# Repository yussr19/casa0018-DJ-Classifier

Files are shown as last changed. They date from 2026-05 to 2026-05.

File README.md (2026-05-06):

# DJ Sound Classifier — CASA0018

<div align="center">

**Author:** yussr19  
**GitHub:** [casa0018-DJ-Classifier](https://github.com/yussr19/casa0018-DJ-Classifier)  
**Edge Impulse Project:** [Public Project Link](https://studio.edgeimpulse.com/public/965867/live)

<br>

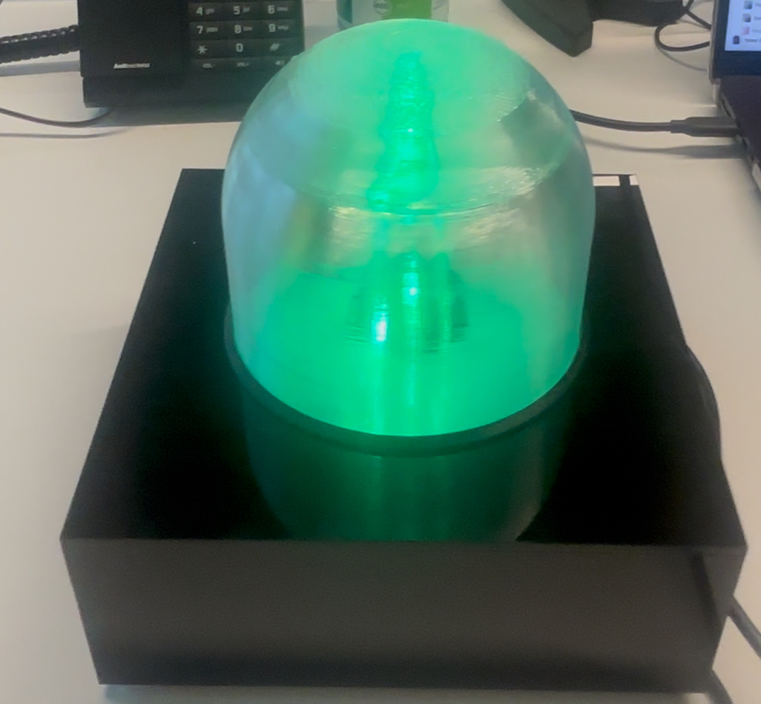
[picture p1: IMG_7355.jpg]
DJ Sound Classifier enclosure


*Custom 3D-printed enclosure showing a control noise (green) classification*

</div>

---

# Overview

The **DJ Sound Classifier** is a real-time embedded audio classification system that detects acoustic events in DJ sets and triggers reactive LED lighting effects entirely on-device — no cloud connection required.

The system classifies three audio events:

| Class | LED Response |
|---|---|
| **Bass drop** | 🔵 Blue chasing effect |
| **Kick drop** | 🔴 Solid red |
| **Control noise** | 🟢 Solid green |

---

# Motivation

The UK's grassroots music venue scene has faced a prolonged financial crisis, with over 125 venues closing in 2023 alone due to rising operational costs, including professional lighting and production systems.

This project explores whether **edge machine learning** can provide a low-cost alternative to commercial audio-reactive lighting systems for resource-constrained venues.

---

# Hardware

| Component | Details | Approx. Cost |
|---|---|---|
| Arduino Nano 33 BLE Sense | Microcontroller with onboard microphone | £35 |
| WS2812B NeoPixel Strip (16 LEDs) | Addressable RGB LEDs | £5 |
| 3×AA Battery Pack | 4.5V power supply | £2 |
| 330Ω Resistor | Data-line protection | <£1 |
| 100µF Capacitor | Power smoothing | <£1 |
| Breadboard + Jumper Wires | Circuit assembly | £3 |
| 3D Printed Enclosure | `DOME.stl` + `light_boxx.stl` | ~£2 |

**Estimated total cost:** ~£48

---

# Reproducing the Project

## Step 1 — Print the Enclosure

Print both STL files from the `/enclosure` folder:

- `light_boxx.stl` — base housing for the Arduino and breadboard
- `DOME.stl` — light-diffusing dome cover

### Recommended Settings

- PLA
- 0.2mm layer height
- 20% infill

For best diffusion, print the dome using **white or translucent filament**.

---

# Step 2 — Assemble the Circuit

## Wiring Diagram

```text
Battery (+) ─────────────────────────────── LED Strip 5V
Battery (-) ─────────────────────────────── LED Strip GND
Battery (-) ─────────────────────────────── Arduino GND

Capacitor (+) ───────────────────────────── LED Strip 5V
Capacitor (-) ───────────────────────────── LED Strip GND

Arduino D6 ─── 330Ω resistor ───────────── LED Strip DIN
```

### Important Notes

- The **330Ω resistor** protects the first LED from voltage spikes.
- The **100µF capacitor** stabilises the power rail and prevents brownouts or Arduino resets.
- All components must share a **common ground**.

Place the Arduino and breadboard inside `light_boxx.stl`, then wrap the LED strip around the inside of the dome.

---

# Step 3 — Set Up Edge Impulse

You can either use the pretrained model or retrain the system from scratch.

---

## Option A — Use the Existing Model (Recommended)

1. Open the public Edge Impulse project:  
   https://studio.edgeimpulse.com/public/965867/live

2. Click **Clone this project**

3. Navigate to:

```text
Deployment → Arduino Library → Build
```

4. Download the generated ZIP library.

---

## Option B — Retrain the Model

### Install Edge Impulse CLI

```bash
npm install -g edge-impulse-cli
edge-impulse-daemon --clean
```

### Collect Data

Record:
- 2-second samples
- 16kHz mono WAV
- ~115 samples per class

### Classes

| Class | Description |
|---|---|
| `bass_drop` | Sustained bass-heavy sections |
| `kick_drop` | Rhythmic kick drum patterns |
| `control_noise` | Ambient crowd/room noise |

---

## Create the Impulse

### Input Parameters

- Window size: 2000ms
- Window increase: 500ms
- Frequency: 16000Hz

### Processing Block

```text
Audio (MFE)
```

### Learning Block

```text
Classification
```

---

## MFE Parameters

| Parameter | Value |
|---|---|
| Frame length | 0.02 |
| Frame stride | 0.01 |
| Filters | 6 |
| FFT length | 256 |
| Low frequency | 0 |
| High frequency | 300 |

---

## Training Settings

| Parameter | Value |
|---|---|
| Epochs | 100 |
| Learning rate | 0.005 |
| Batch size | 32 |
| Data augmentation | Off |

### Keras Expert Mode

Update the reshape layer:

```python
Reshape((int(input_length / 6), 6))
```

---

# Step 4 — Install Arduino Libraries

## Install NeoPixel Library

Arduino IDE:

```text
Tools → Manage Libraries → Adafruit NeoPixel → Install
```

## Install Edge Impulse Library

```text
Sketch → Include Library → Add .ZIP Library
```

Select the ZIP downloaded from Edge Impulse.

---

# Step 5 — Upload the Arduino Sketch

1. Open:

```text
DJ_LED2/DJ_LED2.ino
```

2. Select board:

```text
Arduino Nano 33 BLE Sense
```

3. Select the correct port and click **Upload**

---

## Optional: Upload via bossac

```bash
ls /dev/cu.usbmodem*

bossac -p /dev/cu.usbmodem[PORT] -e -w -v -R DJ_LED2.ino.bin
```

---

# Step 6 — Power and Test

1. Disconnect USB
2. Connect the 3×AA battery pack
3. The LEDs flash white on startup to confirm the system is active

## Test Responses

| Audio Event | LED Behaviour |
|---|---|
| Bass-heavy music | 🔵 Blue chasing |
| Kick-heavy patterns | 🔴 Solid red |
| Ambient noise / silence | 🟢 Solid green |

> Best performance occurs when positioned approximately 30–50cm from the speaker.

---

# ML Model Details

| Feature | Value |
|---|---|
| Platform | Edge Impulse |
| Project ID | 965867 |
| Preprocessing | MFE, 300Hz LPF |
| Filters | 6 |
| FFT Length | 256 |
| Architecture | 1D CNN |
| Deployment | INT8 quantised (EON Compiler) |
| RAM Usage | 13.8KB |
| Flash Usage | 46.5KB |
| Inference Time | ~5ms |

---

# Dataset

| Class | Samples |
|---|---|
| bass_drop | 116 |
| kick_drop | 115 |
| control_noise | 115 |
| **Total** | **346** |

### Dataset Split

- 80% training
- 20% testing

---

# Results Summary

| Experiment | Accuracy | Weighted F1 |
|---|---|---|
| Broadband Spectrogram | 30.0% | 0.14 |
| MFE 200Hz | 52.9% | 0.51 |
| **MFE 300Hz (Best)** | **57.1%** | **0.58** |
| MFE 500Hz | 57.1% | 0.57 |
| MFCC Broadband | 52.9% | 0.53 |
| MFCC 300Hz | 44.3% | 0.42 |
| Venue Test 1 | 21.74% | 0.37 |
| Venue Test 2 | 35.71% | 0.46 |

---

# Known Limitations

- Significant domain gap between home and live venue recordings
- Kick drops overlap spectrally with bass drops below 300Hz
- Environmental acoustics reduce reliability in crowded venues
- Direct mixer line-in would substantially improve performance

---

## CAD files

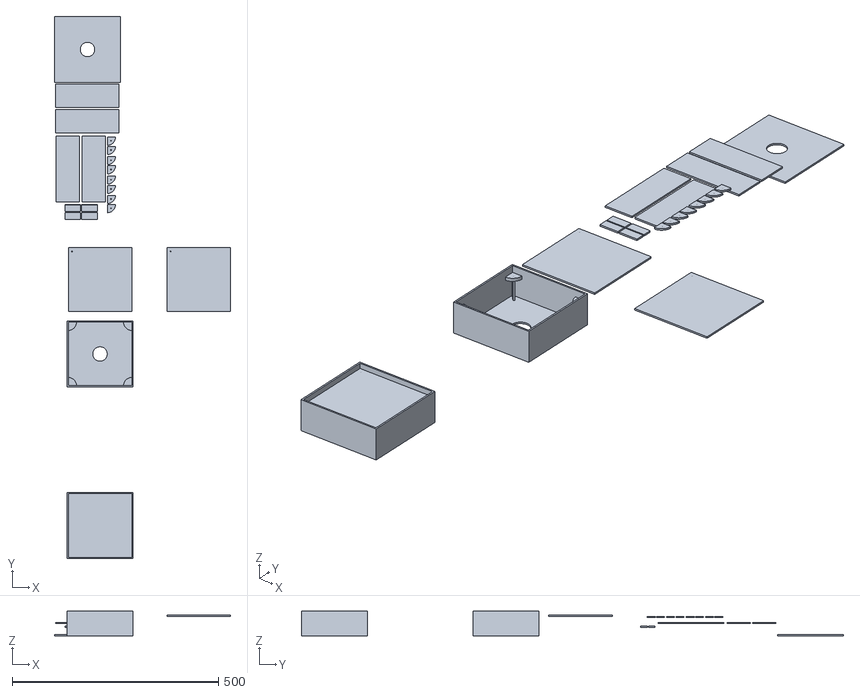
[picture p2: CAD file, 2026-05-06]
enclosure /light boxx.stl
426.5 x 1312.9 x 60.0

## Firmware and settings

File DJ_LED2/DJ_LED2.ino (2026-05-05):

#define EIDSP_QUANTIZE_FILTERBANK 0
#include <DJ_classifier_casa0018_inferencing.h>
#include <PDM.h>
#include <Adafruit_NeoPixel.h>

#define LED_PIN 6
#define LED_COUNT 16
Adafruit_NeoPixel strip(LED_COUNT, LED_PIN, NEO_GRB + NEO_KHZ800);

typedef struct {
    int16_t *buffer;
    uint8_t buf_ready;
    uint32_t buf_count;
    uint32_t n_samples;
} inference_t;

static inference_t inference;
static signed short sampleBuffer[2048];
static bool debug_nn = false;

static void pdm_data_ready_inference_callback(void)
{
    int bytesAvailable = PDM.available();
    int bytesRead = PDM.read((char *)&sampleBuffer[0], bytesAvailable);
    if (inference.buf_ready == 0) {
        for(int i = 0; i < bytesRead>>1; i++) {
            inference.buffer[inference.buf_count++] = sampleBuffer[i];
            if(inference.buf_count >= inference.n_samples) {
                inference.buf_count = 0;
                inference.buf_ready = 1;
                break;
            }
        }
    }
}

static bool microphone_inference_start(uint32_t n_samples)
{
    inference.buffer = (int16_t *)malloc(n_samples * sizeof(int16_t));
    if(inference.buffer == NULL) { return false; }
    inference.buf_count = 0;
    inference.n_samples = n_samples;
    inference.buf_ready = 0;
    PDM.onReceive(&pdm_data_ready_inference_callback);
    PDM.setBufferSize(4096);
    if (!PDM.begin(1, EI_CLASSIFIER_FREQUENCY)) {
        ei_printf("Failed to start PDM!");
        free(inference.buffer);
        return false;
    }
    PDM.setGain(127);
    return true;
}

static bool microphone_inference_record(void)
{
    inference.buf_ready = 0;
    inference.buf_count = 0;
    while(inference.buf_ready == 0) { delay(10); }
    return true;
}

static int microphone_audio_signal_get_data(size_t offset, size_t length, float *out_ptr)
{
    numpy::int16_to_float(&inference.buffer[offset], out_ptr, length);
    return 0;
}

void setup()
{
    Serial.begin(115200);
    strip.begin();
    strip.setBrightness(80);
    strip.fill(strip.Color(255, 255, 255));
    strip.show();
    delay(1000);
    strip.clear();
    strip.show();
    if (microphone_inference_start(EI_CLASSIFIER_RAW_SAMPLE_COUNT) == false) {
        ei_printf("ERR: Could not allocate audio buffer\r\n");
        return;
    }
}

void loop()
{
    bool m = microphone_inference_record();
    if (!m) { return; }
    signal_t signal;
    signal.total_length = EI_CLASSIFIER_RAW_SAMPLE_COUNT;
    signal.get_data = &microphone_audio_signal_get_data;
    ei_impulse_result_t result = { 0 };
    EI_IMPULSE_ERROR r = run_classifier(&signal, &result, debug_nn);
    if (r != EI_IMPULSE_OK) { return; }
    float maxVal = 0;
    int maxIdx = 0;
    for (int i = 0; i < EI_CLASSIFIER_LABEL_COUNT; i++) {
        ei_printf("%s: %.5f\n", result.classification[i].label, result.classification[i].value);
        if (result.classification[i].value > maxVal) {
            maxVal = result.classification[i].value;
            maxIdx = i;
        }
    }
    if (maxIdx == 0) {
        // bass drop - blue chase effect
        for(int j = 0; j < 3; j++) {
            for(int i = 0; i < LED_COUNT; i++) {
                strip.clear();
                strip.setPixelColor(i, strip.Color(0, 0, 255));
                strip.setPixelColor((i + LED_COUNT/2) % LED_COUNT, strip.Color(0, 0, 128));
                strip.show();
                delay(30);
            }
        }
    } else if (maxIdx == 2) {
        strip.fill(strip.Color(255, 0, 0));
        strip.show();
    } else {
        strip.fill(strip.Color(0, 255, 0));
        strip.show();
    }
}

#if !defined(EI_CLASSIFIER_SENSOR) || EI_CLASSIFIER_SENSOR != EI_CLASSIFIER_SENSOR_MICROPHONE
#error "Invalid model for current sensor."
#endif

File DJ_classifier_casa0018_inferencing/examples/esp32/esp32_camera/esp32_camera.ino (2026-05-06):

/* Edge Impulse Arduino examples
 * Copyright (c) 2022 EdgeImpulse Inc.
 *
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
 * THE SOFTWARE IS PROVIDED "AS IS", WITHOUT WARRANTY OF ANY KIND, EXPRESS OR
 * IMPLIED, INCLUDING BUT NOT LIMITED TO THE WARRANTIES OF MERCHANTABILITY,
 * FITNESS FOR A PARTICULAR PURPOSE AND NONINFRINGEMENT. IN NO EVENT SHALL THE
 * AUTHORS OR COPYRIGHT HOLDERS BE LIABLE FOR ANY CLAIM, DAMAGES OR OTHER
 * LIABILITY, WHETHER IN AN ACTION OF CONTRACT, TORT OR OTHERWISE, ARISING FROM,
 * OUT OF OR IN CONNECTION WITH THE SOFTWARE OR THE USE OR OTHER DEALINGS IN THE
 * SOFTWARE.
 */

// These sketches are tested with 2.0.4 ESP32 Arduino Core
// https://github.com/espressif/arduino-esp32/releases/tag/2.0.4

/* Includes ---------------------------------------------------------------- */
#include <DJ_classifier_casa0018_inferencing.h>
#include "edge-impulse-sdk/dsp/image/image.hpp"

#include "esp_camera.h"

// Select camera model - find more camera models in camera_pins.h file here
// https://github.com/espressif/arduino-esp32/blob/master/libraries/ESP32/examples/Camera/CameraWebServer/camera_pins.h

#define CAMERA_MODEL_ESP_EYE // Has PSRAM
//#define CAMERA_MODEL_AI_THINKER // Has PSRAM

#if defined(CAMERA_MODEL_ESP_EYE)
#define PWDN_GPIO_NUM    -1
#define RESET_GPIO_NUM   -1
#define XCLK_GPIO_NUM    4
#define SIOD_GPIO_NUM    18
#define SIOC_GPIO_NUM    23

#define Y9_GPIO_NUM      36
#define Y8_GPIO_NUM      37
#define Y7_GPIO_NUM      38
#define Y6_GPIO_NUM      39
#define Y5_GPIO_NUM      35
#define Y4_GPIO_NUM      14
#define Y3_GPIO_NUM      13
#define Y2_GPIO_NUM      34
#define VSYNC_GPIO_NUM   5
#define HREF_GPIO_NUM    27
#define PCLK_GPIO_NUM    25

#elif defined(CAMERA_MODEL_AI_THINKER)
#define PWDN_GPIO_NUM     32
#define RESET_GPIO_NUM    -1
#define XCLK_GPIO_NUM      0
#define SIOD_GPIO_NUM     26
#define SIOC_GPIO_NUM     27

#define Y9_GPIO_NUM       35
#define Y8_GPIO_NUM       34
#define Y7_GPIO_NUM       39
#define Y6_GPIO_NUM       36
#define Y5_GPIO_NUM       21
#define Y4_GPIO_NUM       19
#define Y3_GPIO_NUM       18
#define Y2_GPIO_NUM        5
#define VSYNC_GPIO_NUM    25
#define HREF_GPIO_NUM     23
#define PCLK_GPIO_NUM     22

#else
#error "Camera model not selected"
#endif

/* Constant defines -------------------------------------------------------- */
#define EI_CAMERA_RAW_FRAME_BUFFER_COLS           320
#define EI_CAMERA_RAW_FRAME_BUFFER_ROWS           240
#define EI_CAMERA_FRAME_BYTE_SIZE                 3

/* Private variables ------------------------------------------------------- */
static bool debug_nn = false; // Set this to true to see e.g. features generated from the raw signal
static bool is_initialised = false;
uint8_t *snapshot_buf; //points to the output of the capture

static camera_config_t camera_config = {
    .pin_pwdn = PWDN_GPIO_NUM,
    .pin_reset = RESET_GPIO_NUM,
    .pin_xclk = XCLK_GPIO_NUM,
    .pin_sscb_sda = SIOD_GPIO_NUM,
    .pin_sscb_scl = SIOC_GPIO_NUM,

    .pin_d7 = Y9_GPIO_NUM,
    .pin_d6 = Y8_GPIO_NUM,
    .pin_d5 = Y7_GPIO_NUM,
    .pin_d4 = Y6_GPIO_NUM,
    .pin_d3 = Y5_GPIO_NUM,
    .pin_d2 = Y4_GPIO_NUM,
    .pin_d1 = Y3_GPIO_NUM,
    .pin_d0 = Y2_GPIO_NUM,
    .pin_vsync = VSYNC_GPIO_NUM,
    .pin_href = HREF_GPIO_NUM,
    .pin_pclk = PCLK_GPIO_NUM,

    //XCLK 20MHz or 10MHz for OV2640 double FPS (Experimental)
    .xclk_freq_hz = 20000000,
    .ledc_timer = LEDC_TIMER_0,
    .ledc_channel = LEDC_CHANNEL_0,

    .pixel_format = PIXFORMAT_JPEG, //YUV422,GRAYSCALE,RGB565,JPEG
    .frame_size = FRAMESIZE_QVGA,    //QQVGA-UXGA Do not use sizes above QVGA when not JPEG

    .jpeg_quality = 12, //0-63 lower number means higher quality
    .fb_count = 1,       //if more than one, i2s runs in continuous mode. Use only with JPEG
    .fb_location = CAMERA_FB_IN_PSRAM,
    .grab_mode = CAMERA_GRAB_WHEN_EMPTY,
};

/* Function definitions ------------------------------------------------------- */
bool ei_camera_init(void);
void ei_camera_deinit(void);
bool ei_camera_capture(uint32_t img_width, uint32_t img_height, uint8_t *out_buf) ;

/**
* @brief      Arduino setup function
*/
void setup()
{
    // put your setup code here, to run once:
    Serial.begin(115200);
    //comment out the below line to start inference immediately after upload
    while (!Serial);
    Serial.println("Edge Impulse Inferencing Demo");
    if (ei_camera_init() == false) {
        ei_printf("Failed to initialize Camera!\r\n");
    }
    else {
        ei_printf("Camera initialized\r\n");
    }

    ei_printf("\nStarting continious inference in 2 seconds...\n");
    ei_sleep(2000);
}

/**
* @brief      Get data and run inferencing
*
* @param[in]  debug  Get debug info if true
*/
void loop()
{

    // instead of wait_ms, we'll wait on the signal, this allows threads to cancel us...
    if (ei_sleep(5) != EI_IMPULSE_OK) {
        return;
    }

    snapshot_buf = (uint8_t*)malloc(EI_CAMERA_RAW_FRAME_BUFFER_COLS * EI_CAMERA_RAW_FRAME_BUFFER_ROWS * EI_CAMERA_FRAME_BYTE_SIZE);

    // check if allocation was successful
    if(snapshot_buf == nullptr) {
        ei_printf("ERR: Failed to allocate snapshot buffer!\n");
        return;
    }

    ei::signal_t signal;
    signal.total_length = EI_CLASSIFIER_INPUT_WIDTH * EI_CLASSIFIER_INPUT_HEIGHT;
    signal.get_data = &ei_camera_get_data;

    if (ei_camera_capture((size_t)EI_CLASSIFIER_INPUT_WIDTH, (size_t)EI_CLASSIFIER_INPUT_HEIGHT, snapshot_buf) == false) {
        ei_printf("Failed to capture image\r\n");
        free(snapshot_buf);
        return;
    }

    // Run the classifier
    ei_impulse_result_t result = { 0 };

    EI_IMPULSE_ERROR err = run_classifier(&signal, &result, debug_nn);
    if (err != EI_IMPULSE_OK) {
        ei_printf("ERR: Failed to run classifier (%d)\n", err);
        return;
    }

    // print the predictions
    ei_printf("Predictions (DSP: %d ms., Classification: %d ms., Anomaly: %d ms.): \n",
                result.timing.dsp, result.timing.classification, result.timing.anomaly);

#if EI_CLASSIFIER_OBJECT_DETECTION == 1
    ei_printf("Object detection bounding boxes:\r\n");
    for (uint32_t i = 0; i < result.bounding_boxes_count; i++) {
        ei_impulse_result_bounding_box_t bb = result.bounding_boxes[i];
        if (bb.value == 0) {
            continue;
        }
        ei_printf("  %s (%f) [ x: %u, y: %u, width: %u, height: %u ]\r\n",
                bb.label,
                bb.value,
                bb.x,
                bb.y,
                bb.width,
                bb.height);
    }

    // Print the prediction results (classification)
#else
    ei_printf("Predictions:\r\n");
    for (uint16_t i = 0; i < EI_CLASSIFIER_LABEL_COUNT; i++) {
        ei_printf("  %s: ", ei_classifier_inferencing_categories[i]);
        ei_printf("%.5f\r\n", result.classification[i].value);
    }
#endif

    // Print anomaly result (if it exists)
#if EI_CLASSIFIER_HAS_ANOMALY
    ei_printf("Anomaly prediction: %.3f\r\n", result.anomaly);
#endif
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

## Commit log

2026-04-25 test code for LED
2026-04-27 Add LED control to sketch LED strip responds to DJ audio classification (bass=blue, kick=red, control=green)
